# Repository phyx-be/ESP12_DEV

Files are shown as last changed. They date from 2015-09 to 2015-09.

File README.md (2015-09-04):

# ESP12_DEV
A development board for the ESP12 and ESP12E WiFi modules. Featuring some useful sensors and required peripherals to make it work.

## Rev 00

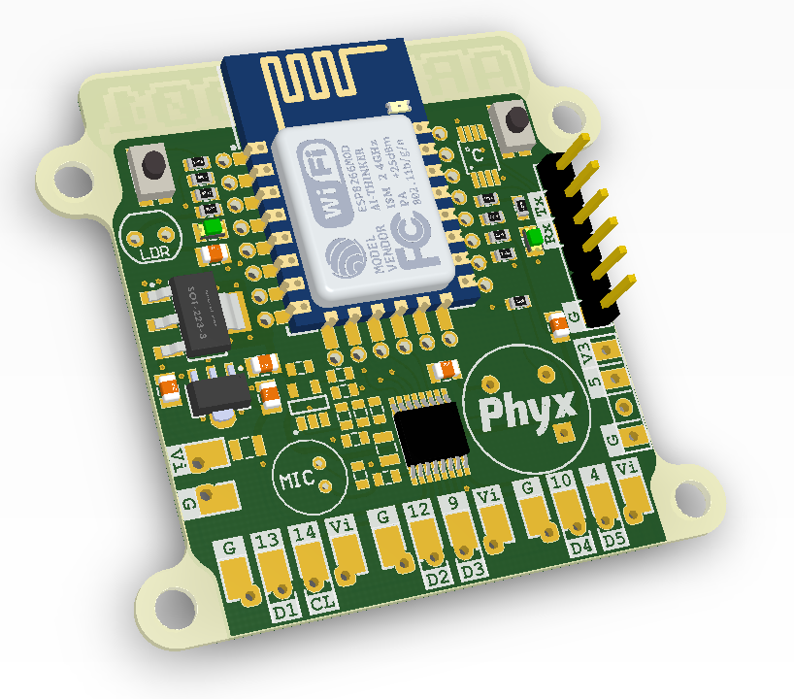
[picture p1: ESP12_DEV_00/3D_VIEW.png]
ESP12_DEV_00


Initial board version with 3.3V LDO and 5V LDO. 
#### Known issues : 
- TXB0106 symbol is wrong resulting in a short circuit
- 3V3 LDO will get hot when board is powered with 12V

## Rev 01

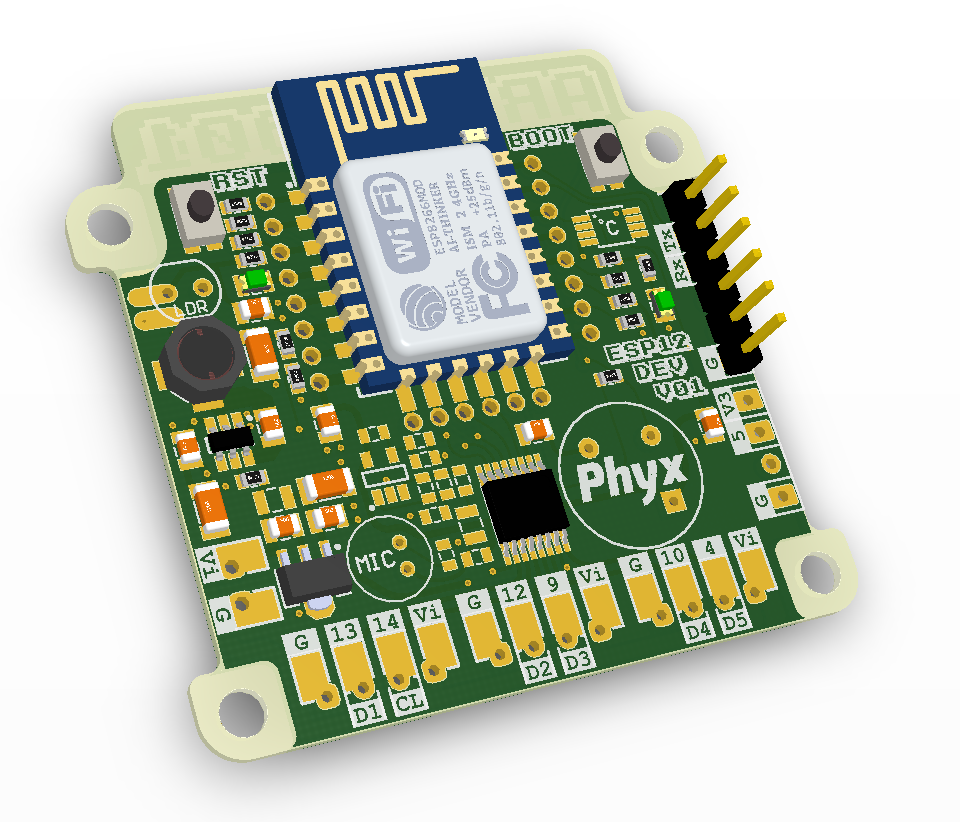
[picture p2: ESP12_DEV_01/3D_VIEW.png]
ESP12_DEV_01


- Replaced the 3.3V LDO with a [TPS562209](http://www.ti.com/product/tps562209) based switching power supply to reduce power dissipation.
- Added more capacitors to increase stability

## Features

- 3V3 level FTDI-compatible UART pin header
- push buttons for reset and boot
- 7 - 12VDC power input
- 5V power input possible when bypassing internal 5V LDO with 0 Ohm resistor or ferrite bead.
- 6 bidirectional 5V I/O pins
- Microphone
- Temperature and humidity sensor

Component | Description | Notes | IO pin
----------|-------------|-------|--------
[TXB0106](http://www.ti.com/product/txb0106) | 6 bit level translator | Interfacing with 5V I/O | 4,9,10,12,13,14
[DS18B20](http://www.maximintegrated.com/en/products/analog/sensors-and-sensor-interface/DS18B20.html) | 1-Wire temperature sensor | Shares pin with DHT11 | 5
[DHT11](http://www.aosong.com/en/products/details.asp?id=109) | Temperature and humidity sensor | Shares pin with DS18B20 | 5
LED | General purpose LED | | 16
[EKMC1601113](http://na.industrial.panasonic.com/products/sensors/sensors-automotive-industrial-applications/pir-motion-sensor-papirs/series/vz-series/2481) | Digital motion detection | Shares I/O pin with TXB0106 | 4
MIC | Electret Microphone with amplifier circuit | ADC has max input of 1V | ADC

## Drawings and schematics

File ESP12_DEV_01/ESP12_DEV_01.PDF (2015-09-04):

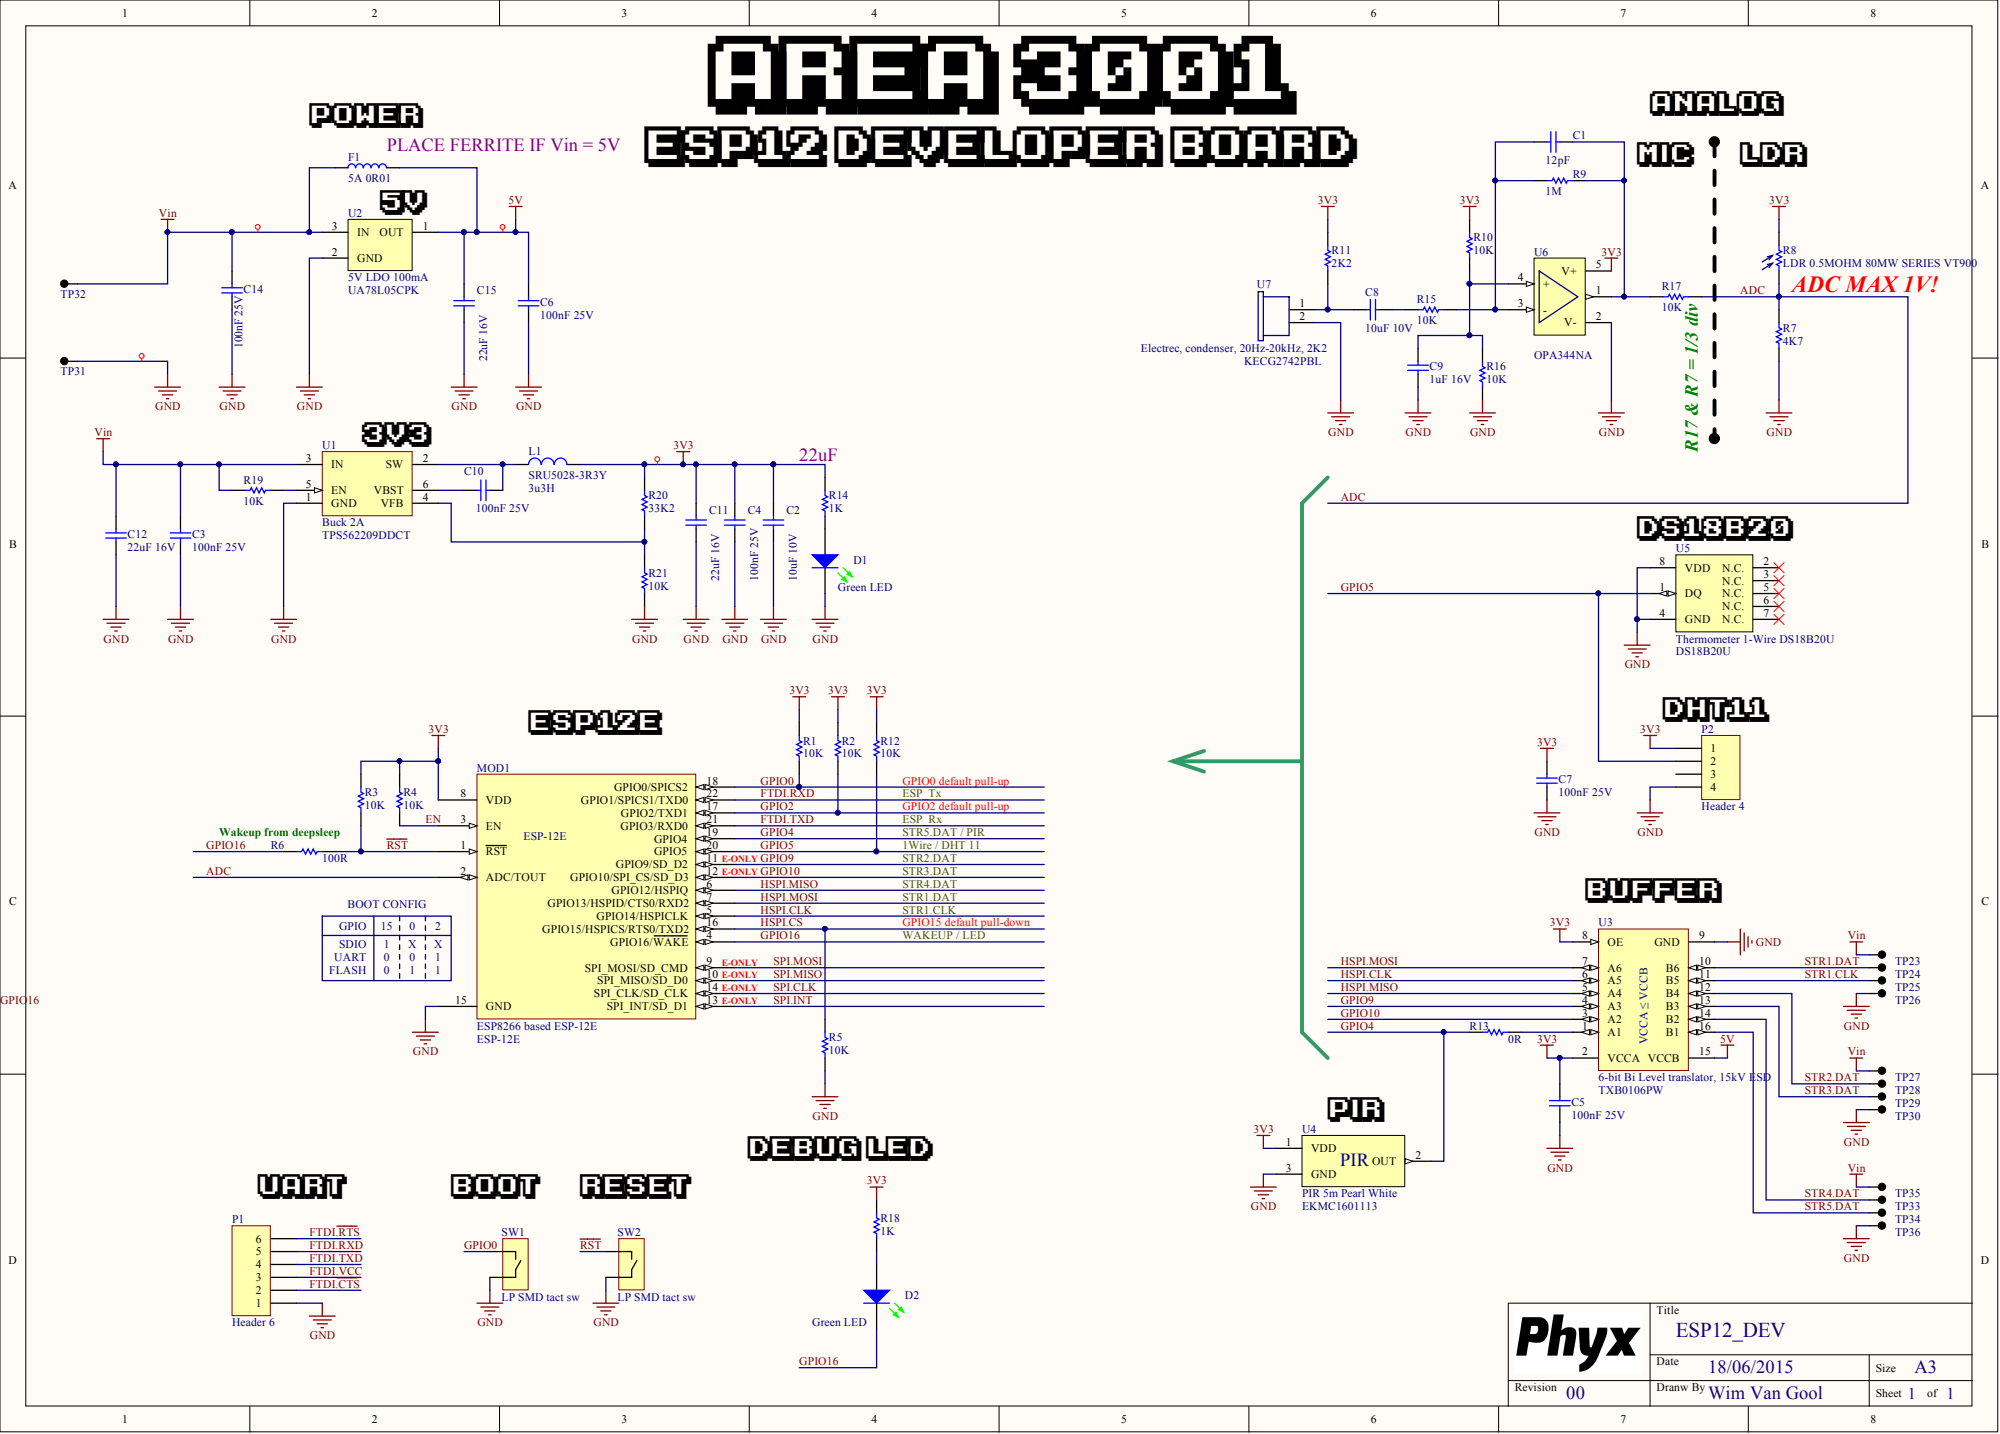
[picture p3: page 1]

GPIO | 1 5 | 0 | 2
SDIO UART FL ASH | 1 0 0 | X 10 | X 1 1

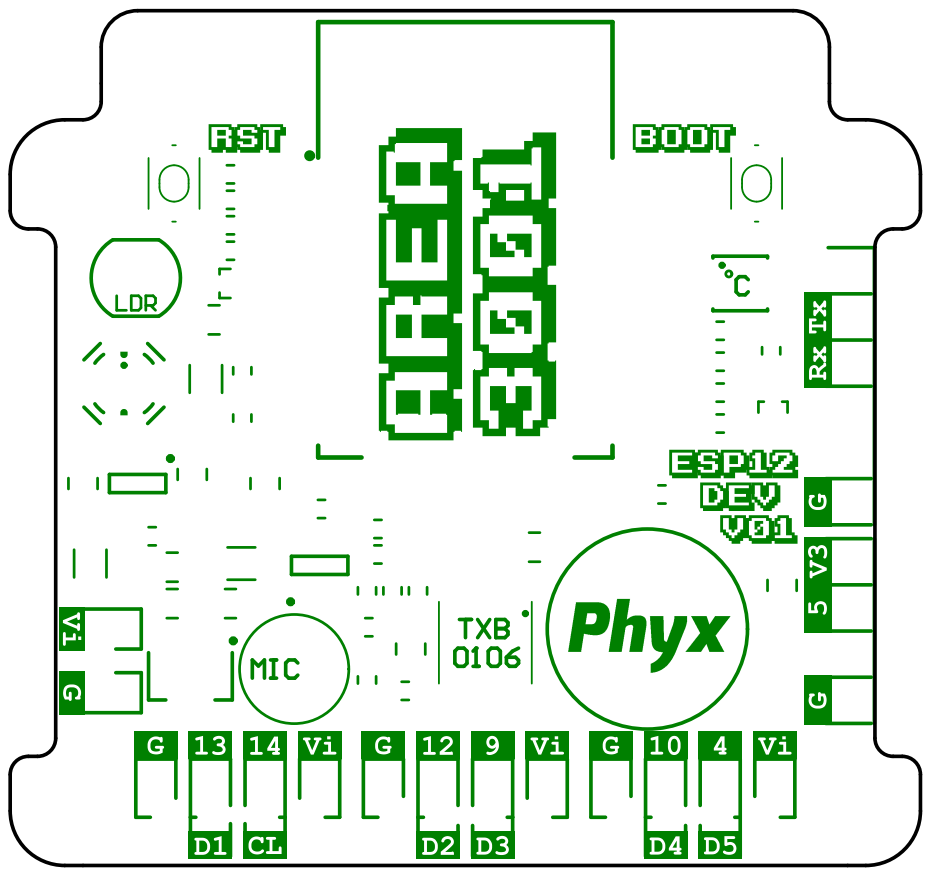
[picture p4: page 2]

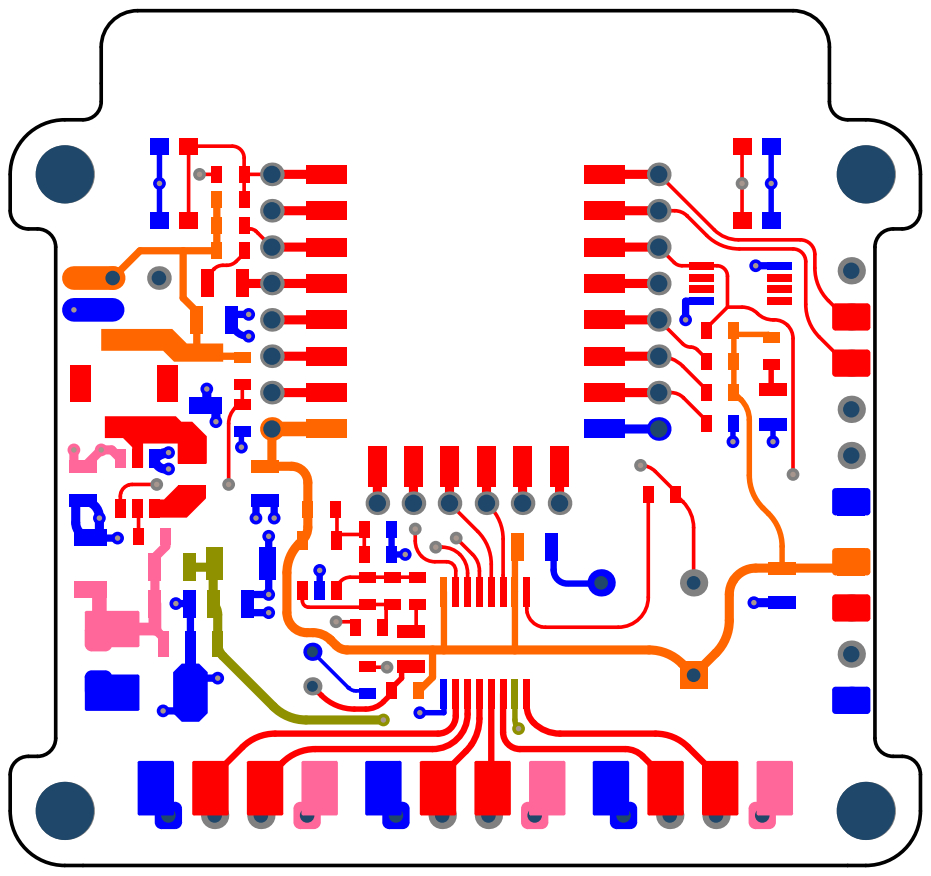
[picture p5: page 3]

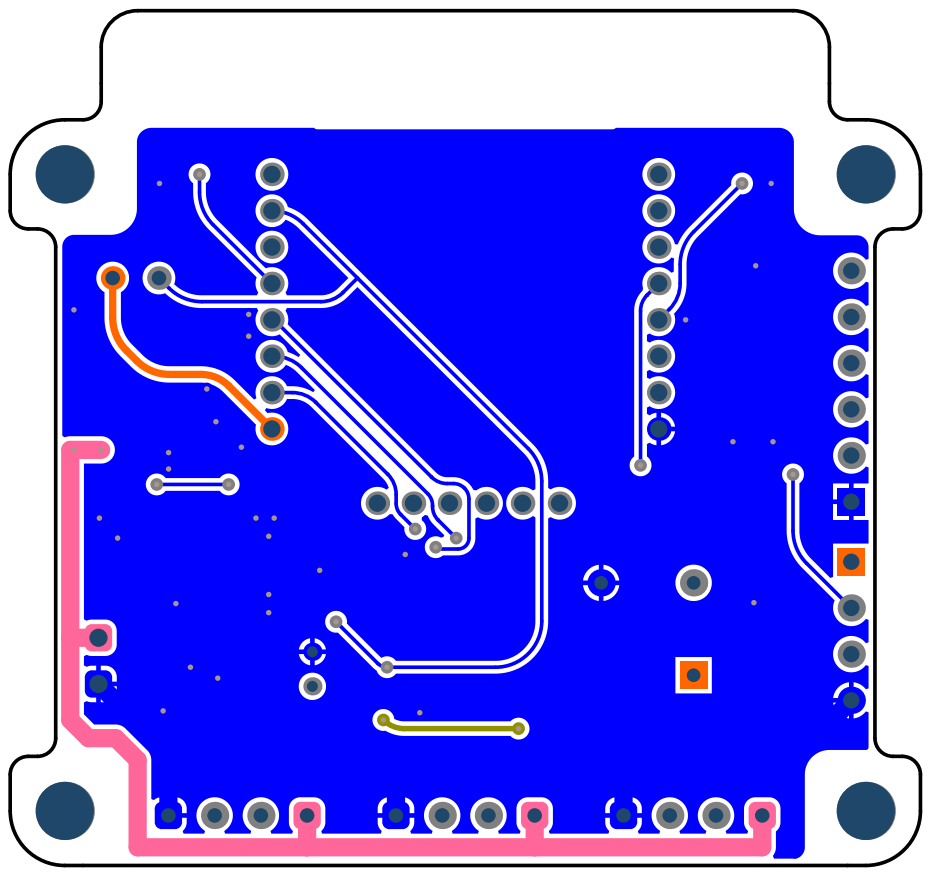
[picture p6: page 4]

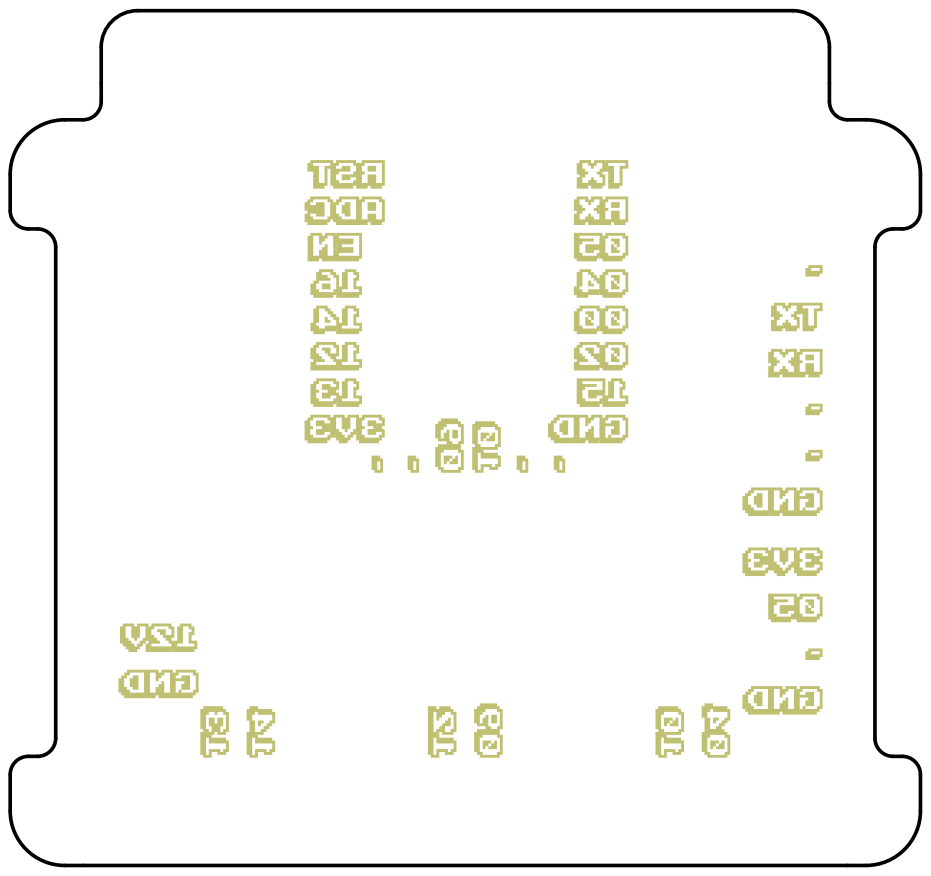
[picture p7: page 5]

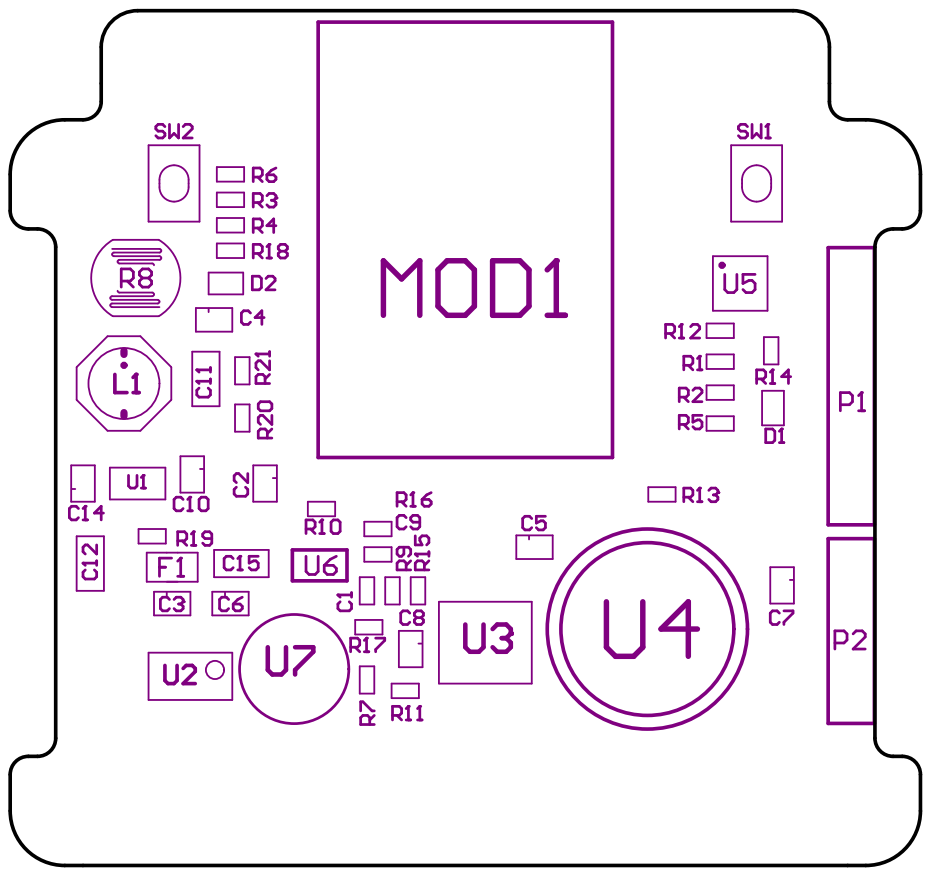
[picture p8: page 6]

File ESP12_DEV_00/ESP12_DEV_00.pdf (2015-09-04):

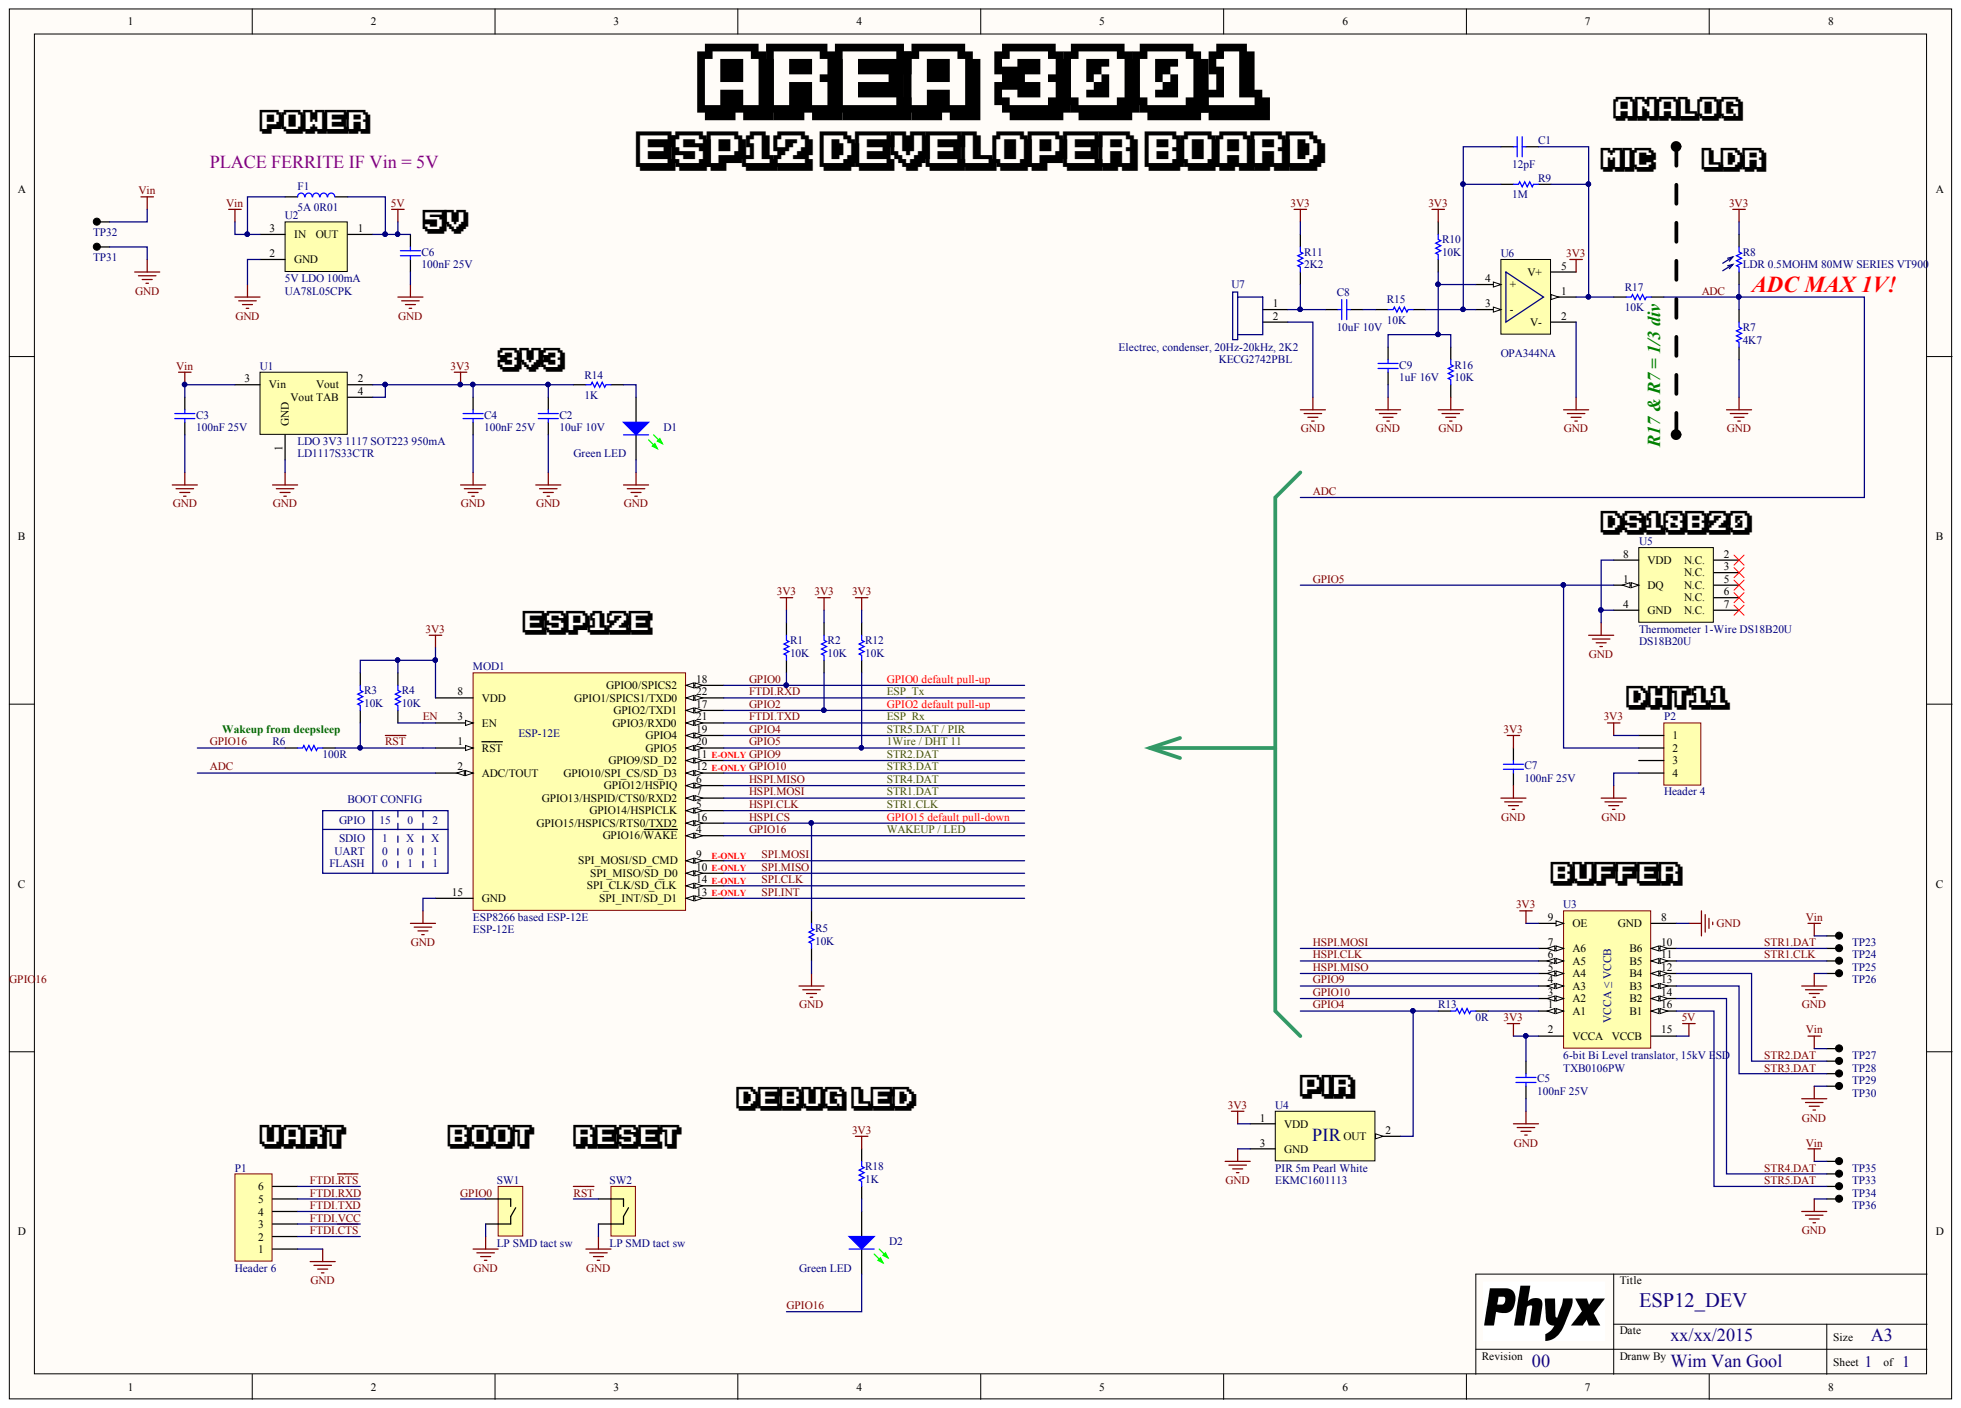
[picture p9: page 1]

ASHBOO GPI O | 15 | 0 | 2

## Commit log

2015-09-04 Design files added
    [ESP12_DEV_00.PrjPcb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]
2015-09-04 Images added
    Added 3D views from both PCBs and updated the readme file
